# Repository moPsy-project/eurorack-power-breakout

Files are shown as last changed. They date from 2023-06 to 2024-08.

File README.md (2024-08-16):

# Eurorack Power Breakout

> Breakout board for Eurorack power on the breadboard

* Reverse polarity protection diodes
* Basic filtering on the power supply lines
* Selection for 5V/GND on one of the power rails
* Breakout for CV and Gate line from the extended bus
* Uses THT for easy assembly

## Dependencies

This project uses symbols from the [moPsy-KiCad-resources](https://github.com/moPsy-project/moPsy-KiCad-resources).

Please note that the paths in the `-lib-table` files most likely do not fit your setup and need to be adapted.

## License



This work is licensed under a [Creative Commons Attribution-ShareAlike 4.0 International License](http://creativecommons.org/licenses/by-sa/4.0/).

BY: Stefan Haun (mail@tuxathome.de)

See [LICENSE.txt](LICENSE.txt) for details.

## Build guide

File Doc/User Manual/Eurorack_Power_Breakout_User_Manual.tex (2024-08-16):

\documentclass[a4paper,
               11pt,
               parskip=half,
               headinclude,
               titlepage=false]{scrartcl}

%%%%%%%%%%%%%%%%%%%%%%%%%%%%%%%%%%%%%%%%
\newcommand{\metaauthor}{moPsy}
\newcommand{\metatitle}{Eurorack Power Breakout User Manual}
\newcommand{\metarev}{1.2}
%%%%%%%%%%%%%%%%%%%%%%%%%%%%%%%%%%%%%%%%

\usepackage[utf8]{inputenc}

\usepackage[T1]{fontenc}        % Tries to use Postscript Type 1 Fonts for better rendering
\usepackage{lmodern}            % Provides the Latin Modern Font which offers more glyphs than the default Computer Modern
\usepackage[sfdefault]{carlito}
\usepackage[intlimits]{amsmath} % Provides all mathematical commands
\usepackage[protrusion=true,
            expansion,
            kerning=true,
            babel=true]{microtype}
\usepackage{fontawesome}

\usepackage[english]{babel}
\usepackage[english]{isodate}

\usepackage{eurosym}
\usepackage[shortlabels]{enumitem}

\usepackage{grffile}            % Allow you to include images (like graphicx). Usage: \includegraphics{path/to/file}

\usepackage[ugly]{units}        % Allows you to type units with correct spacing and font style. Usage: $\unit[100]{m}$ or $\unitfrac[100]{m}{s}$

\usepackage{xspace}             % Use \xpsace in macros to automatically insert space based on context. Usage: \newcommand{\es}{ESPResSo\xspace}
\usepackage[dvipsnames,table]{xcolor}             % Obviously colors. Usage: \color{red} Red text
\usepackage{booktabs}           % Nice rules for tables. Usage \begin{tabular}\toprule ... \midrule ... \bottomrule

%\usepackage[hang]{subfigure}  % unterteilte Abbildungen
\usepackage{setspace}          %fuer dem Zeilanabstand
\usepackage[hang,bf,footnotesize]{caption}   % bessere Bildunterschriften
\usepackage{wrapfig}

\usepackage{csquotes}

\usepackage[hyphens]{url}                % Lets you typeset urls. Usage: \url{http://...}
\usepackage[pdftex,colorlinks=true,linkcolor=black,citecolor=black,urlcolor=black]{hyperref}
\hypersetup{
  pdftitle    = {\metatitle},
  pdfsubject  = {Assembly Guide},
  pdfauthor   = {\metaauthor},
  pdfkeywords = {} ,
  pdfcreator  = {pdflatex},
  pdfproducer = {LaTeX with hyperref}
}
%%%%%%%%%%%%%%%%%%%%%%%%%%%%%%%%%%%%%%%%

\usepackage{pdfpages}

\usepackage{tabularx}

\usepackage[headsepline, footsepline]{scrlayer-scrpage}
\setlength{\headheight}{34pt} % logo height
\clearpairofpagestyles
\ohead{
\vfill%
\begin{tabular}{@{}l l@{}}
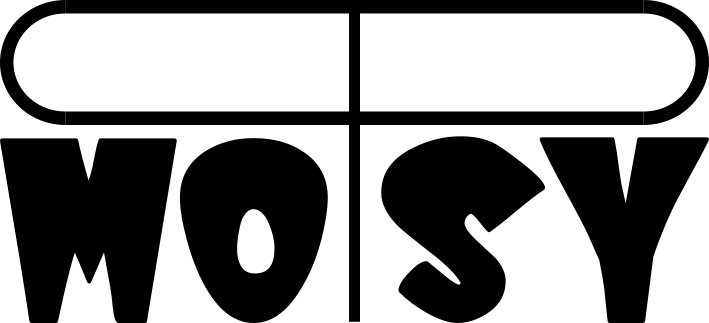
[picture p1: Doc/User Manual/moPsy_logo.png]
\hspace*{-0.1cm}
\end{tabular}
}
\ihead{
\vfill%
{\huge Eurorack Power Breakout} \,v\metarev\, User Manual%
}
\ofoot{Page \thepage}
\setkomafont{pageheadfoot}{\sffamily\footnotesize}
\setkomafont{pagination}{}
\pagestyle{scrheadings}

%\usepackage{background}

%\usepackage[section]{placeins} % keep figures in their section

\definecolor{level_easy}{rgb}{0.2, 0.6, 0.1}

\definecolor{row1}{rgb}{1.0, 1.0, 1.0}
\definecolor{row2}{rgb}{0.93, 0.93, 0.99}

\begin{document}

\begin{minipage}[b]{10.5cm}
\setlength{\parskip}{\medskipamount}
\section*{Thank you for choosing a  product!}

This manual provides information on the \textbf{Eurorack Power Breakout} board.
We hope that all questions will be answered.
If you encounter a problem or have further questions,
please do not hesitate and reach out to us at \href{mailto:contact@mopsy-music.de}{\texttt{contact@mopsy-music.de}}.

%\vspace{1em}
\begin{center}
Enjoy! \quad 
\end{center}

\end{minipage}%
\hspace{0.5cm}
\begin{minipage}[]{4cm}
\vspace{-3cm}
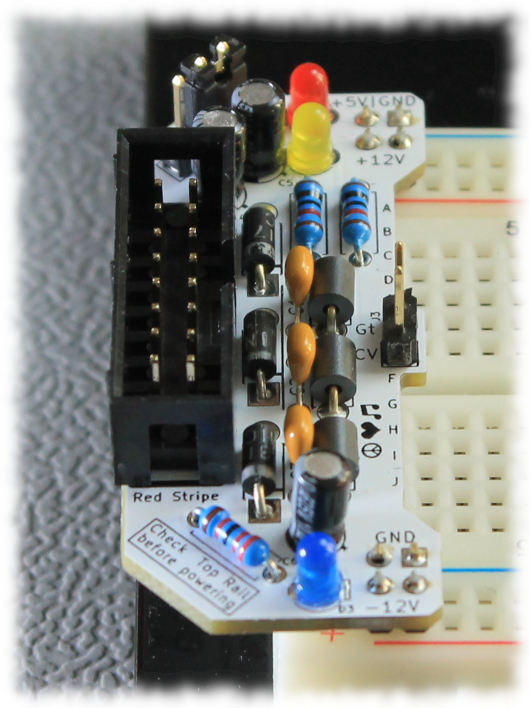
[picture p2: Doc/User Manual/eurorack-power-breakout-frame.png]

\end{minipage}

\vspace{-3em}
\section*{About the Eurorack Power Breakout board}

The \textbf{Eurorack Power Breakout} board provides the Eurorack power bus on a breadboard.
It allows for a \textbf{quick setup} of power supply components, so that you can immediately start prototyping.

The \textbf{main features} are:
\begin{itemize}[noitemsep]
 \item Reverse polarity protection diodes
 \item Basic filtering on the power supply lines
 \item Selection for 5V/GND on one of the power rails
 \item Breakout for CV and Gate signals from the extended bus
\end{itemize}

\section*{Installation}

Install the breakout board on your breadboard power rails as shown in the picture above.
If your board has color markings,
it is beneficial to align the \unit[+12]V/\unit[-12]V pins with the red lines.

To \textbf{connect power} …
\begin{enumerate}[noitemsep]
 \item Please make sure that your cabinet is \textbf{disconnected from the mains} and has no power.
 \item The board is connected with a \textbf{16-pin} (2x8) bus cable.
 \item \textbf{Check your power cable and the polarity.} The coloured (\textbf{\color{red}red}) line on the cable (pin~1) needs to be connected to the \textbf{\unit[-12]{V}} rail.
 \item If you plug the board backwards, it may burn out.
 Unfortunately this cannot be covered by the warranty.
\end{enumerate}

The board itself draws a maximum of \textbf{\unit[2]mA} from each rail.

\begin{minipage}[]{10.5cm}
\setlength{\parskip}{\medskipamount}
\section*{Setup and Use}

The first step on each use is to set up the \textbf{\color{red}Voltage Selector} (1), which allows you to change the top rail between \textbf{\unit[+5]V} and \textbf{GND} by placing the jumper in the respective position. Do not bridge the outer pins, as this will short your power supply!

Please take extra care of this jumper, as a \textbf{wrong setting may destroy your components!}

%Hence the warning:

\begin{center}
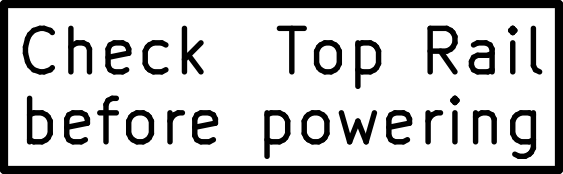
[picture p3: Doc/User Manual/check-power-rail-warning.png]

\end{center}

The \textbf{LEDs} on the board will light up according to selected the voltages,
\textbf{\color{red}RED} for \unit[+5]V, \textbf{\color{orange!80}YELLOW} for \unit[+12]V and \textbf{\color{blue}BLUE} for \unit[-12]V.

\end{minipage}%
\hspace{0.5cm}
\begin{minipage}[]{4cm}
\vspace{-1cm}
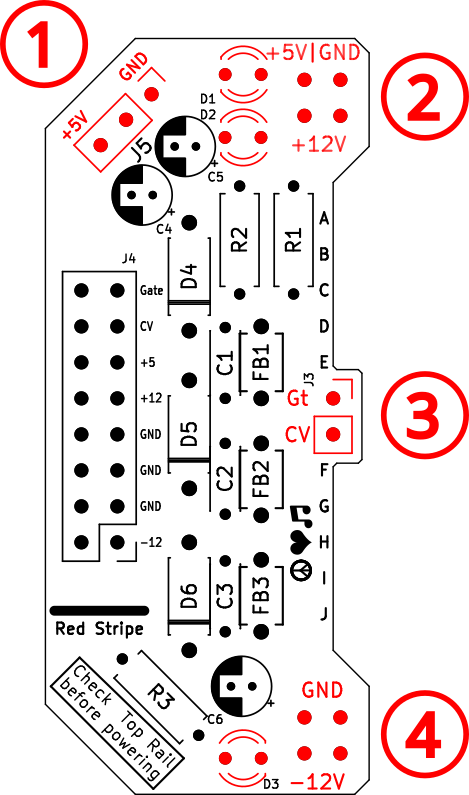
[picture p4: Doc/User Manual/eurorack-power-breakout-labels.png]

\end{minipage}

\vspace{2em}

The board provides the \textbf{Eurorack power lines} on your breadboard power strips with the following configuration:
\begin{itemize}
 \item The \textbf{TOP line} (2) presents \textbf{\color{red}\unit[+5]V} or \textbf{\color{red}GND}, depending on the jumper (1), and \textbf{\color{red}\unit[+12]V}.
 \item The \textbf{BOTTOM line} (4) presents \textbf{\color{red}GND} and \textbf{\color{red}\unit[+12]V}.
\end{itemize}

If there are markings on the breadboard, the labels should align.

\vspace{2em}

The \textbf{MIDDLE line} (3) presents \textbf{\color{red}Bus Gate} and \textbf{\color{red}Bus CV}.

Please note that the \textbf{input/output configuration} of these signals depends on your application and is not influenced by the breakout board.

\section*{Online Resources}

More about the board  …
\begin{itemize}[noitemsep]
 \item on my website: \url{https://www.mopsy-music.de/tools/eurorackpowerbreakout}
 \item on GitHub: \url{https://github.com/moPsy-project/eurorack-power-breakout}
 \item via e-mail: \href{mailto:contact@mopsy-music.de}{\texttt{contact@mopsy-music.de}}
\end{itemize}

\end{document}

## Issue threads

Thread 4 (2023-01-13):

:bug: PCB does not fit on Breadboard

penguineer, 2023-01-13:
The breadboard contacts are a bit off. It will be usable, but this needs fixing.

penguineer, 2023-01-13:
https://www.pololu.com/product/4000

Apparently the bus strips are not within the raster.

penguineer, 2023-01-13:
Positioning is still not fixed... printer scaling is a thing. -.-

Closed 2023-01-13.

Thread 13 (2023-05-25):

:art: Replace switch by jumper

penguineer, 2023-05-25:
Replace the 5V/GND switch by a jumper.

The currently used switch is not very reliable on constant use and it is hard to see what the actual switch position is. Also, changing this voltage is not needed too often.

Use a jumper instead, which is much easier to source and clearly shows the connection.

Closed 2023-11-23.

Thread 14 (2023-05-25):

:art: Turn power connector 180°

penguineer, 2023-05-25:
Turn the power connector around so that -12V (red stripe) are on the bottom side and the direction also matches the outputs.

As a side-effect, the notch is on the "outside", which matches the intuition when plugging in cables.

penguineer, 2023-11-23:
The red stripe is already at the bottom side. The only way to get the notch to face outside is by moving the connector to the right, i.e. mirroring the board. This is a complete redesign and it might then interfere with the right hand.

Not sure if the change is actually worth the effort.

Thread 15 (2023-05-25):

:memo: Create a user manual

penguineer, 2023-05-25:
Create a (very short) user manual  the power breakout board.

Closed 2024-08-16.

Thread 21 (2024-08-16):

Explore zero drop diodes

penguineer, 2024-08-16:
Using FETs, it is possible to build a diode without voltage drop. Explore this option for the next revision.

penguineer, 2024-08-16:
https://components101.com/articles/design-guide-pmos-mosfet-for-reverse-voltage-polarity-protection

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

penguineer, 2024-08-16:
[IRF 9530](https://www.reichelt.de/index.html?ARTICLE=8807) - MOSFET, P-Kanal, -100V, -12A, RDS(on) 0,3 Ohm, TO-220AB

penguineer, 2024-08-16:
Biggest issue is that viable p-channel MOSFETs for THT come in the TO-220 form factor, which makes them not very suitable for the specific application.

Ideally there would be a TO-92 or similar device with U_DS > 12V,  U_gs > 12V (to drop the Zener), I_D > 1.5A and very low RDS_on.

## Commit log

2023-01-05 :sparkles: Add KiCAD project and circuit draft
    [eurorack-power-breakout.kicad_pcb, eurorack-power-breakout.kicad_sch]
2023-01-05 :sparkles: Populate parts as far as available
    [eurorack-power-breakout.kicad_sch]
2023-01-05 :sparkles: Assign component designators
    [eurorack-power-breakout.kicad_sch]
2023-01-06 :bug: Fix annotations and power socket
    [eurorack-power-breakout.kicad_sch]
2023-01-06 :art: Remove fixer pin headers and extend pwr headers
    Unfortunately the alignment on Breadboards is not perfect, so with most
    boards the solution woult not fit.
    [eurorack-power-breakout.kicad_sch]
2023-01-06 :art: Use better footprint for the ferrite beads
    [eurorack-power-breakout.kicad_sch]
2023-01-06 :hammer: Assign a different switch and adapt symbol
    SPDT Symbol does not match the switch pin numbering, so it had to
    be changed here.
    [eurorack-power-breakout.kicad_sch]
2023-01-06 :hammer: Adapt schematic for better routing
    [eurorack-power-breakout.kicad_sch]
2023-01-06 :sparkles: Add PCB design
    [eurorack-power-breakout.kicad_pcb]
2023-01-06 :bug: Fix spacing on PCB-breadboard edge
    [eurorack-power-breakout.kicad_pcb]
2023-01-06 :art: Center the slide switch on the border
    [eurorack-power-breakout.kicad_pcb]
2023-01-06 :art: Make labels on Bus socket shorter
    It is still unclear if these labels will be visible. We will find out
    [eurorack-power-breakout.kicad_pcb]
2023-01-06 :sparkles: Add rivision marker and board meta data
    [eurorack-power-breakout.kicad_pcb]
2023-01-06 :art: Move J1 designator to be symmetrical to J2
    [eurorack-power-breakout.kicad_pcb]
2023-01-06 :bug: Fix resistor footprint
    Accidentally chose 204 instead of 207
    [eurorack-power-breakout.kicad_pcb, eurorack-power-breakout.kicad_sch]
2023-01-06 :wrench: Settings made by the JLCPCB exporter
    [eurorack-power-breakout.kicad_pcb]
2023-01-13 :art: Rotate designators for R3 and FB3
    Cosmetic fix
    [eurorack-power-breakout.kicad_pcb]
2023-01-13 :art: Fix position of OSHW symbol
    [eurorack-power-breakout.kicad_pcb]
2023-01-13 :bookmark: Update the revision tag
    [eurorack-power-breakout.kicad_pcb, eurorack-power-breakout.kicad_sch]
2023-01-13 :bug: Fix connector positioning and adjust dimensions
    Fix posistions according to https://www.pololu.com/product/4000
    [eurorack-power-breakout.kicad_pcb]
2023-01-13 :bug: Adjust positions based on printouts
    Even the pololou model was not perfect, adjust by another 0.005"
    Fixes: #4
    [eurorack-power-breakout.kicad_pcb]
2023-01-13 :art: Minor improvements to routing
    [eurorack-power-breakout.kicad_pcb]
2023-01-13 :hammer: Refill copper pours
    [eurorack-power-breakout.kicad_pcb]
2023-01-13 :pencil2: Fix vertical alignment of power connectors
    [eurorack-power-breakout.kicad_pcb]
2023-01-13 :pencil2: Fix label positions
    [eurorack-power-breakout.kicad_pcb]
2023-01-13 :art: Add peace-love-music logo
    [eurorack-power-breakout.kicad_pcb]
2023-01-13 :art: Change remaining visible designators to 0.6mm height
    [eurorack-power-breakout.kicad_pcb]
2023-01-25 :wrench: Set LED current limiting resistors
    Based on experimentation
    [eurorack-power-breakout.kicad_sch]
2023-01-25 :bug: Fix direction of blue LED
    [eurorack-power-breakout.kicad_pcb, eurorack-power-breakout.kicad_sch]
2023-01-25 :bug: Fix order of GND/+5V for voltage select
    The switch has different switching behavior than expected when I designed the PCB.
    [eurorack-power-breakout.kicad_pcb]
2023-01-25 :art: Make some more space around the power connector
    [eurorack-power-breakout.kicad_pcb]
2023-01-26 :art: Make room for a box pwr connector
    The courtyard drawing is not 100% exact, but sufficient for this
    application.
    [eurorack-power-breakout.kicad_pcb]
2023-03-13 :arrow_up: Upgrade to Kicad 7
    [eurorack-power-breakout.kicad_pcb, eurorack-power-breakout.kicad_sch]
2023-03-13 :ok_hand: Fix DRC findings
    [eurorack-power-breakout.kicad_pcb]
2023-06-28 :bento: Add photo of the board in action
2023-06-28 :bento: Add the "check power settings" warning label
2023-11-23 Replace power switch by jumpers in the schematic
    [eurorack-power-breakout.kicad_sch]
2023-11-23 Adapt PCB to schematic changes
    [eurorack-power-breakout.kicad_pcb]
2023-11-25 Change URL to moPsy website
    [eurorack-power-breakout.kicad_pcb]
2023-11-25 Add the moPsiOct label
    [eurorack-power-breakout.kicad_pcb]
2023-11-25 Add the moPsy logo
    [eurorack-power-breakout.kicad_pcb]
2023-11-25 Adjust the revision number to 1.2
    [eurorack-power-breakout.kicad_pcb]
2024-08-16 Update gitignore for current KiCad versions
    This follows advice
    from https://www.reddit.com/r/KiCad/comments/ungko4/which_files_needs_to_be_stored_in_version_control/
    and https://github.com/github/gitignore/blob/main/KiCad.gitignore
2024-08-16 Update the board drawing
2024-08-16 Update the board photo
